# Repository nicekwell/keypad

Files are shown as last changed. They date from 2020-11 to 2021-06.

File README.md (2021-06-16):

一个可以把键盘和触摸板固定在一起的架子，满足我奇特的需求。

keypad.FCStd：base和盖板的freeCAD工程  
padbed.FCStd：track下面垫板的freeCAD工程。用于把trackpad再往上垫高一点。  

3D打印机打印尺寸限制，把base和cover（盖板）切割成了4个部分，在out目录里分别输出4个模型文件。

适配的磁铁尺寸是：长10mm，宽5mm，厚2mm

## 1. 痛点

* macbook的键盘不好用，喜欢自己买的键盘。
* macbook的触摸板好用

想要同时使用自己买的键盘和macbook的trackpad：
* 把自己的键盘放在macbook上
  * 优点：可以同时使用自己的键盘和macbook的触摸板
  * 缺点：自己的键盘比较高，按某些按键时会需要抬起手腕，长时间使用会不舒服。同时由于macbook触摸板在键盘下方，不方便加手托。
* macbook放一边，买了外置的trackpad
  * 优点：键盘可以加手托了
  * 缺点：外置trackpad放在键盘侧边，使用不方便。如果把trackpad放在键盘下方，由于外置trackpad比较大，容易误触。

## 2. 我的需求

1. 使用外置键盘
2. 键盘下有较高的手托
3. trackpad放在键盘下方，使用trackpad时手腕有支撑
4. trackpad不能太大，不能误触发

## 3. 键盘和trackpad

* 键盘：  
  NIZ mini84 键  
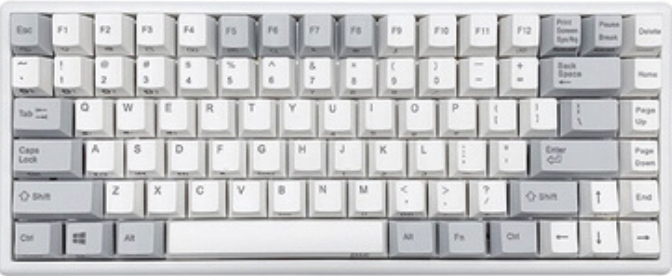
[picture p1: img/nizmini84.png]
    
  长319，宽133，手托高度17
* trackpad：  
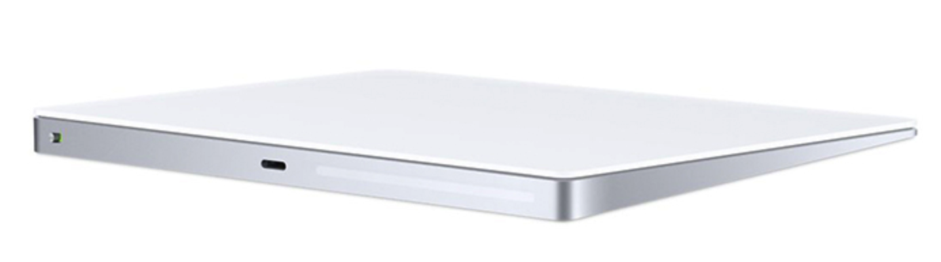
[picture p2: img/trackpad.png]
    
  长160，宽115，高处厚11，低处厚5.6

## 4. 底座要实现的功能

1. 包住键盘
2. 键盘下方合适位置卡住trackpad。
3. trackpad下面有斜坡补偿，trackpad的在上表面要是水平的。
4. trackpad上方有盖子，盖住多余部分，漏出合适大小开口，防止误触同时尽可能增大trackpad使用面积。
5. trackpad和键盘能方便拿下来充电。
6. trackpad的平面高度可以正好充当手托。

## 5. 实现

实现后的模型：

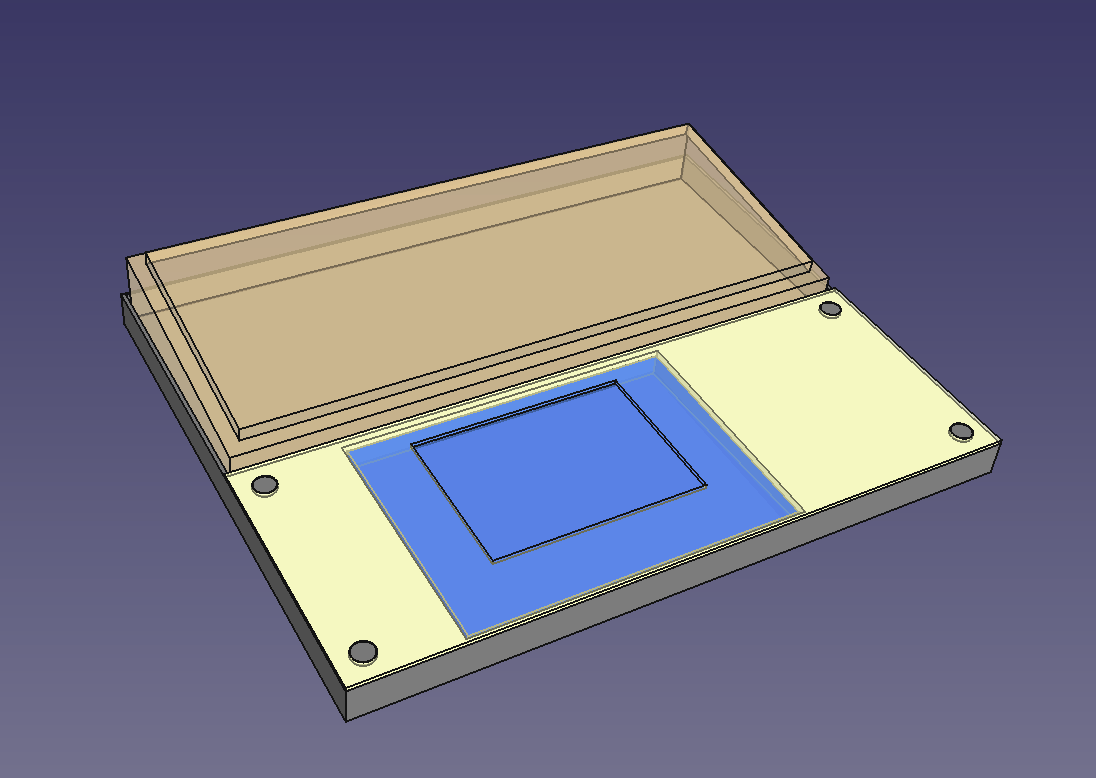
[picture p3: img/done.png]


打印出来效果：

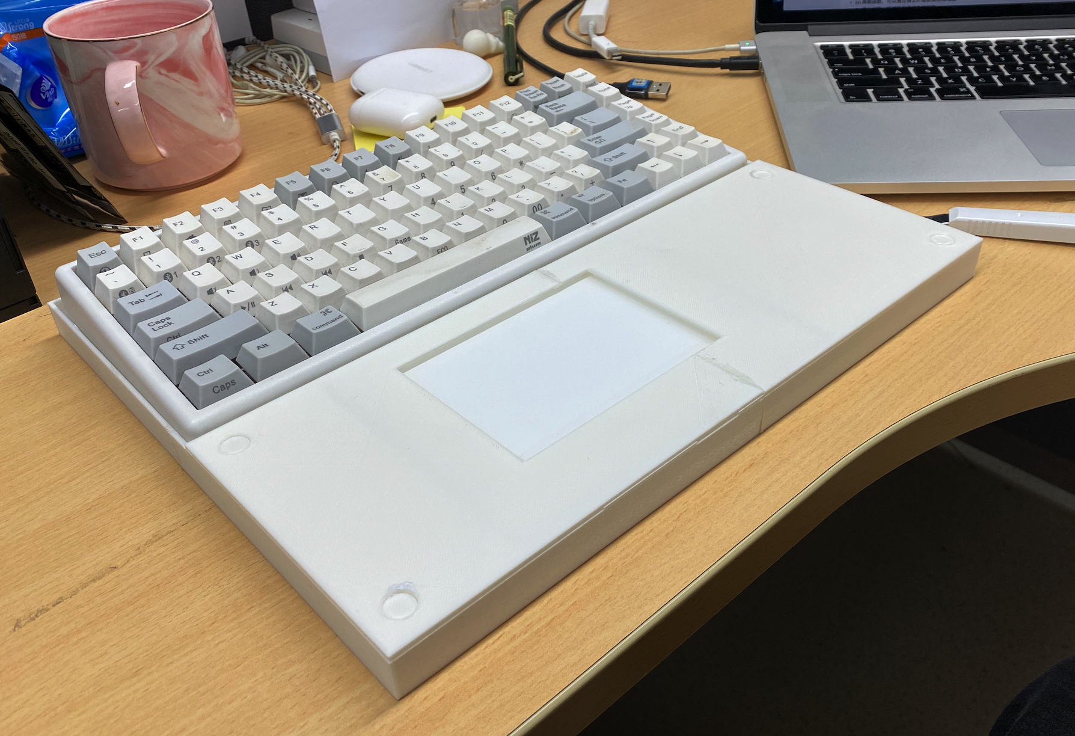
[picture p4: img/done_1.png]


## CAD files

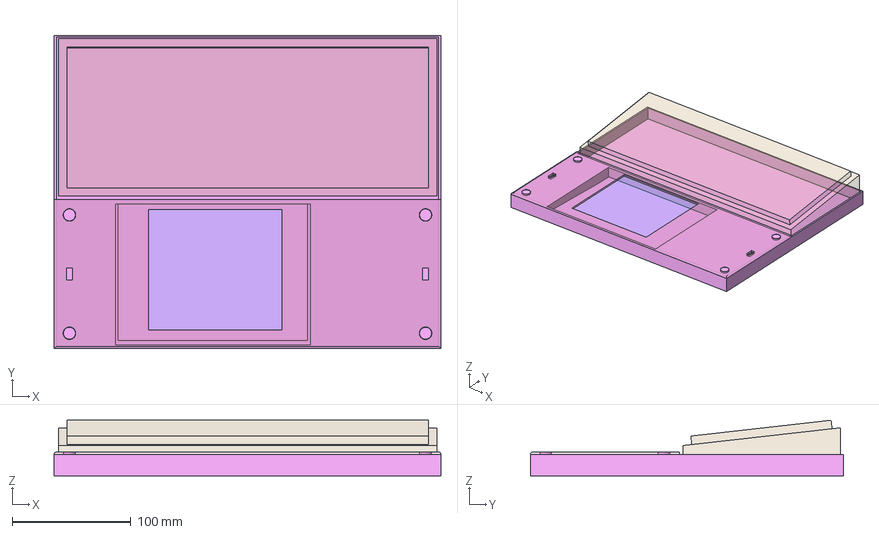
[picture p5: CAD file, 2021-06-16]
keypad.FCStd
326.0 x 263.9 x 46.8 mm
trackpad
keyboard
盖板
base_all

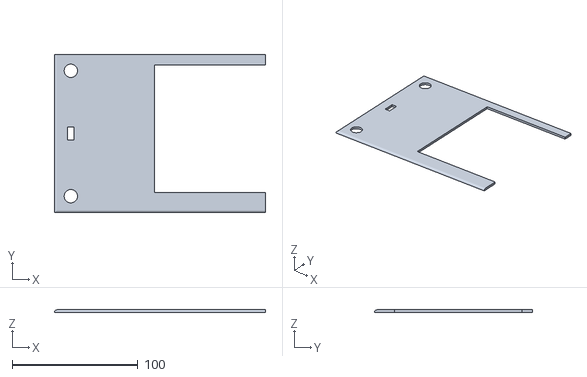
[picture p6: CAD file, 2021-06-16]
out/cover1.stl
167.7 x 125.7 x 2.00

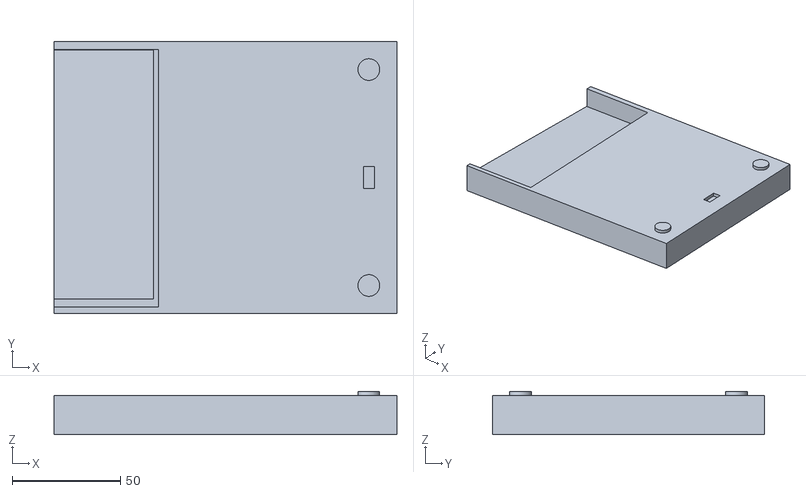
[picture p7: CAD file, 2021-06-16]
out/base_handrest_2.stl
158.3 x 125.7 x 19.9

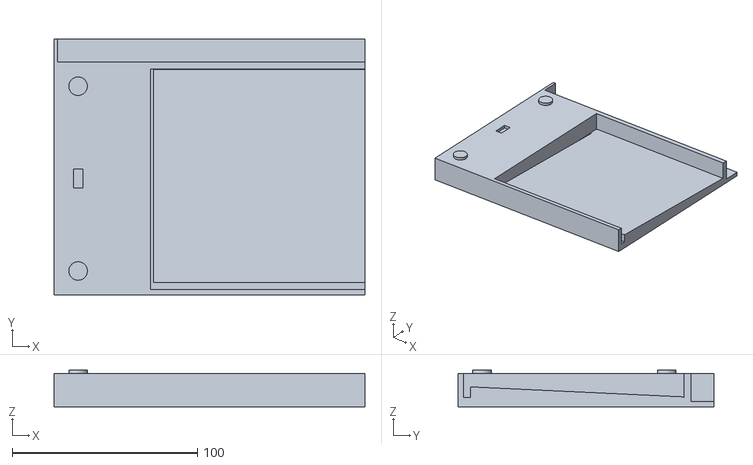
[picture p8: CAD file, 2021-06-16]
out/base1.stl
167.7 x 138.2 x 19.9

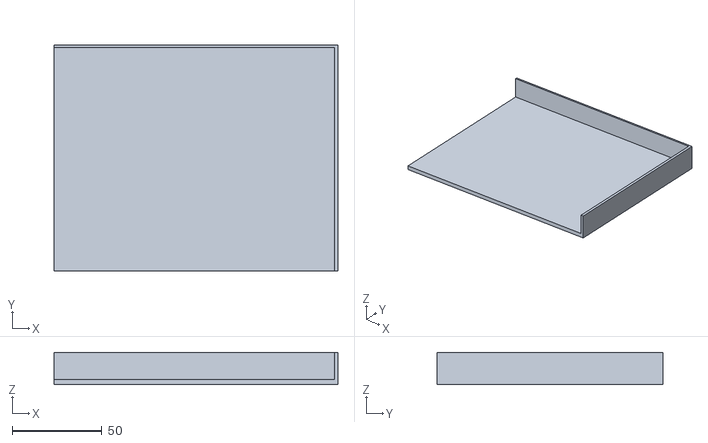
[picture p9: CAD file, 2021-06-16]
out/base4.stl
158.3 x 125.8 x 18.0

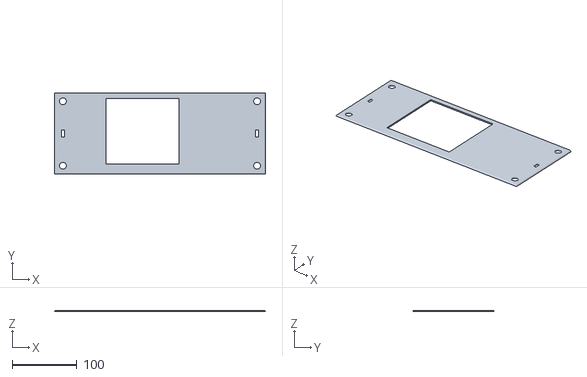
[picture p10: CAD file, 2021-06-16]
out/cover.stl
326.0 x 125.7 x 2.00

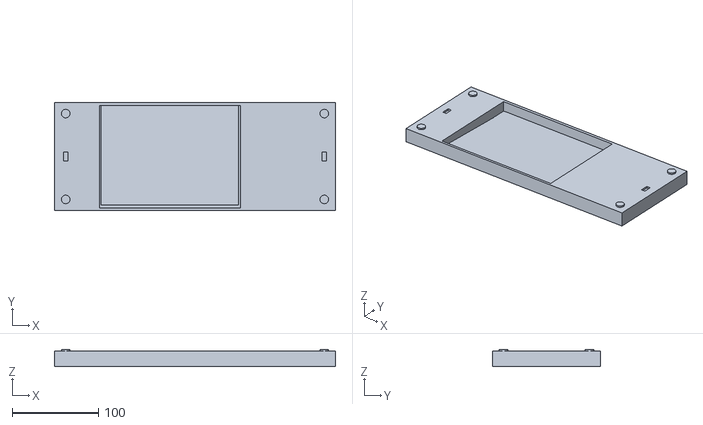
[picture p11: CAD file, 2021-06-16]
out/base_handrest.stl
326.0 x 125.7 x 19.9

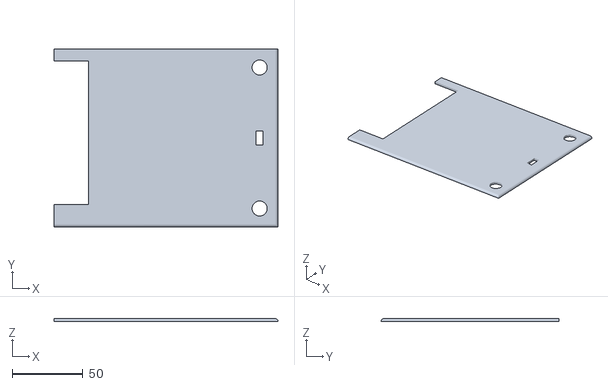
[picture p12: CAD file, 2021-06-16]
out/cover2.stl
158.3 x 125.7 x 2.00

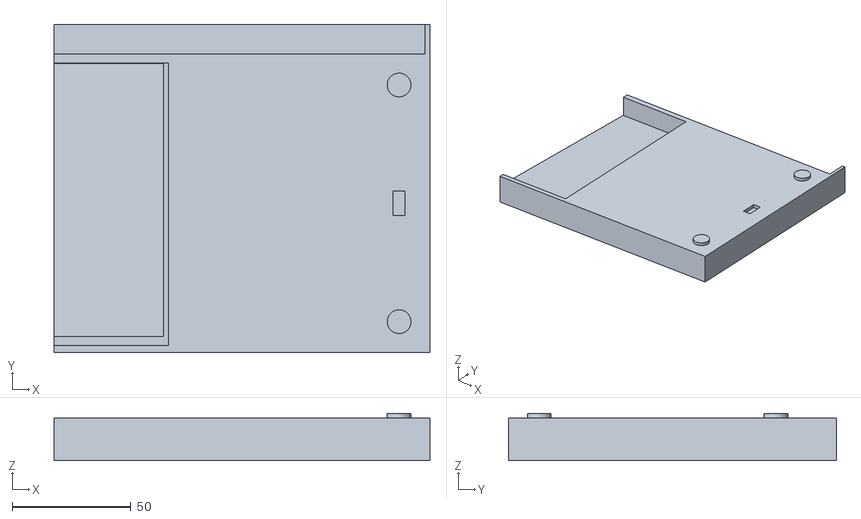
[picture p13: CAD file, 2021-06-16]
out/base2.stl
158.3 x 138.2 x 19.9

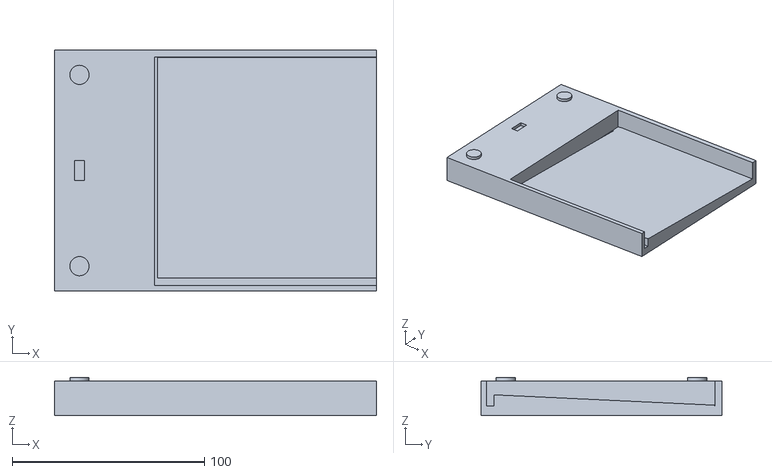
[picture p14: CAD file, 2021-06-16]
out/base_handrest_1.stl
167.7 x 125.7 x 19.9

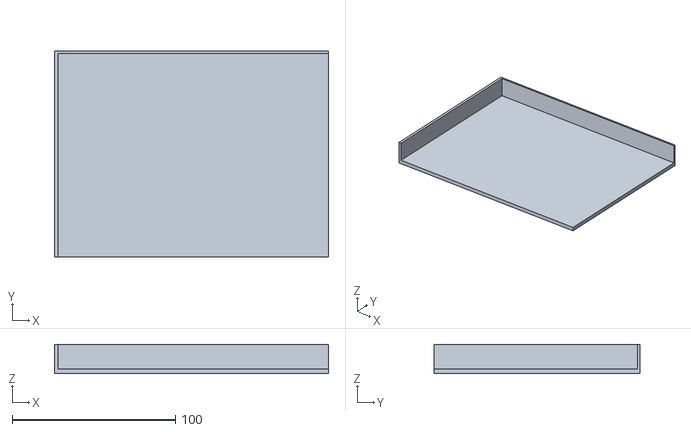
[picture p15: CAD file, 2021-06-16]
out/base3.stl
167.7 x 125.8 x 18.0

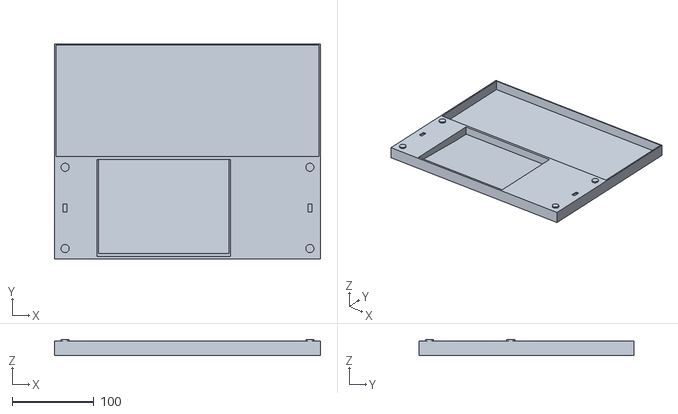
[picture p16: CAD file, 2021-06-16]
out/base.stl
326.0 x 263.9 x 19.9

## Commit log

2020-11-20 readme添加高度
2020-11-20 完成trackpad
    [keypad.FCStd]
2020-11-20 完成键盘
    [keypad.FCStd]
2020-11-20 完成底座，还差盖板。
    [keypad.FCStd]
2020-11-20 完成盖板，剩余：1、底板固定座。2、触摸板上移。
    [keypad.FCStd]
2020-11-20 建模完成，还没打出来测试效果。
    [keypad.FCStd]
2020-11-20 添加切片方块，但斜坡切片还有问题
    [keypad.FCStd]
2020-11-20 完成切片，输出6个stl
    [base1.stl, base2.stl, base3.stl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]
2020-11-23 添加实物照片。
2020-11-25 添加padbed，用于垫在trackpad下方，把trackpad再往上抬高一点。
    [base.stl, cover.stl, padbed.FCStd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]
2020-11-25 扩大trackpad盖板开口面积，使用触摸板面积更大。
    [cover.stl, cover1.stl, cover2.stl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]
2020-11-27 删掉padbed。由于扩大了盖板开口范围，已经能舒适地使用触摸板了，垫高触摸板反而会抵到盖板。 目前的padbed参数：长160，宽116，靠近键盘边厚1.2，靠近人边厚1.8。 目前看来还是稍微有点厚，如果以后还想添加padbed的话建议厚度再减小0.2（用高精度打印）。
    [padbed.FCStd, padbed.stl]
2021-01-19 添加手托部分
    [base_handrest.stl, base_handrest_1.stl, base_handrest_2.stl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]
2021-06-03 盖板添加倒角
    [cover.stl, cover1.stl, cover2.stl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]
2021-06-16 修改盖板和底座，添加 10x5x2 mm的磁铁孔
    [base.stl, base1.stl, base2.stl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]
